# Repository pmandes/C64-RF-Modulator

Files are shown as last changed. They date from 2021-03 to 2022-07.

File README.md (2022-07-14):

# C64-RF-Modulator with S-Video Mod

This is a project of a modulator replacement based on an analog c0pperdragon module. It was adjusted in size to the Commodore C64C motherboard and extended with S-Video and Strereo Audio outputs.

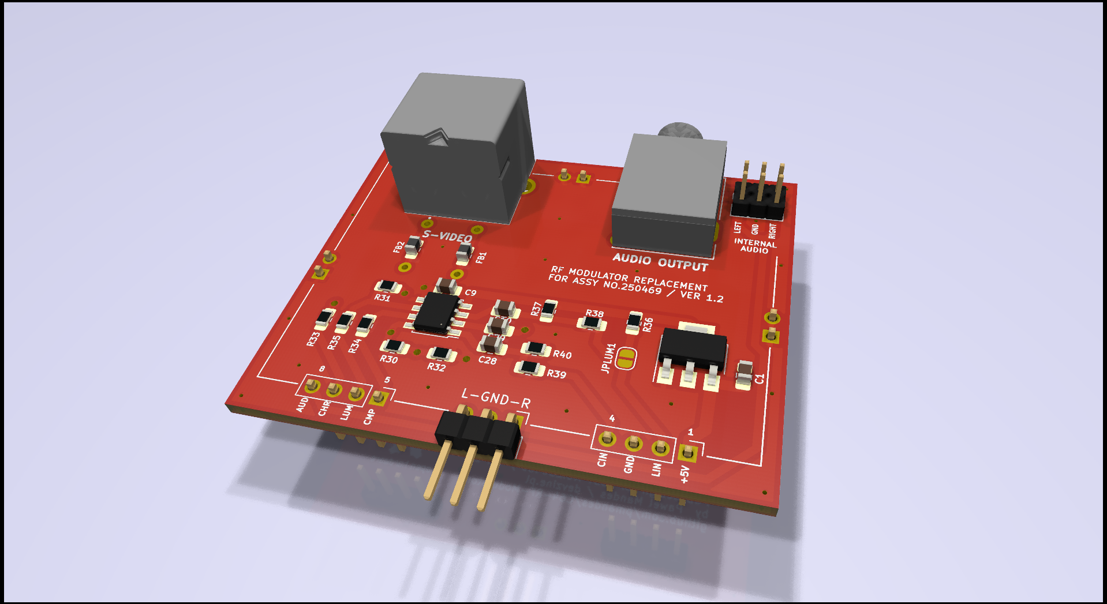
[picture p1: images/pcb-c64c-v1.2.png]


### Changelog:

1.2
- internal audio route to left and/or right channel
- ferrite beads to suppresses high-frequency electronic noise
- silkscreen layer with descriptions of all outputs and elements
- 3D models for a nice rendering
- project cleaned up and migrated to KiCad 6.0
- interactive BOM

1.1
- prototype fixes

1.0
- PCB size adjusted to C64C motherboards (ASSY No.250469)
- S-Video connector added (mini-DIN 4)
- added standard stereo audio mini-jack 3.5mm output

### Bill of materials:

<p align="center">
<a href="https://htmlpreview.github.io/?https://raw.githubusercontent.com/pmandes/C64-RF-Modulator/main/bom/ibom.html
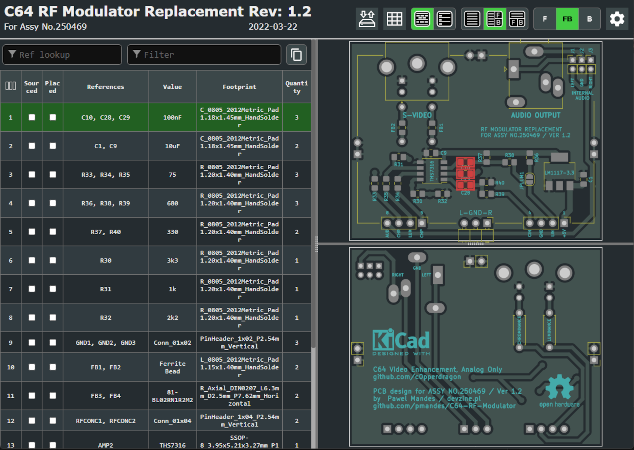
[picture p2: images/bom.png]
"></a>
</p>

### Final revision:

- all jumpers removed: audio output from an external source (e.g. MixSID)
- all jumpers on: mono signal from the motherboard connected to the left and right channels

<p align="center">
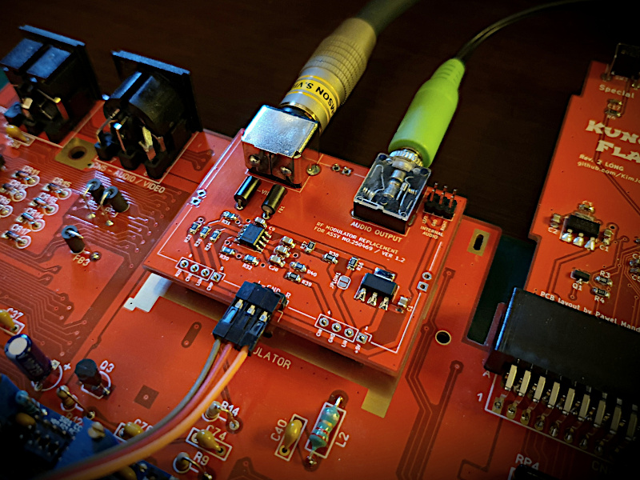
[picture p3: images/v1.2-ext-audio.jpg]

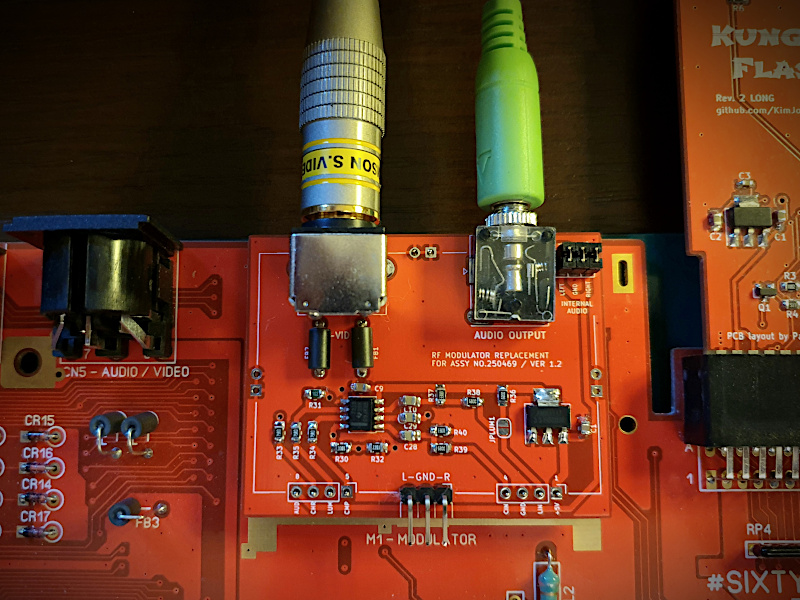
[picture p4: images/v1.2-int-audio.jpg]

</p>

### Prototype images:

The board connected to SixtyClone. Image from S-Video output:

<p align="center">
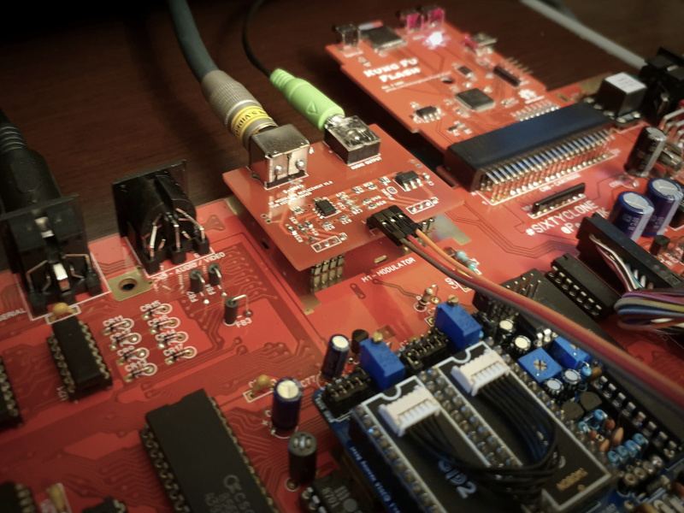
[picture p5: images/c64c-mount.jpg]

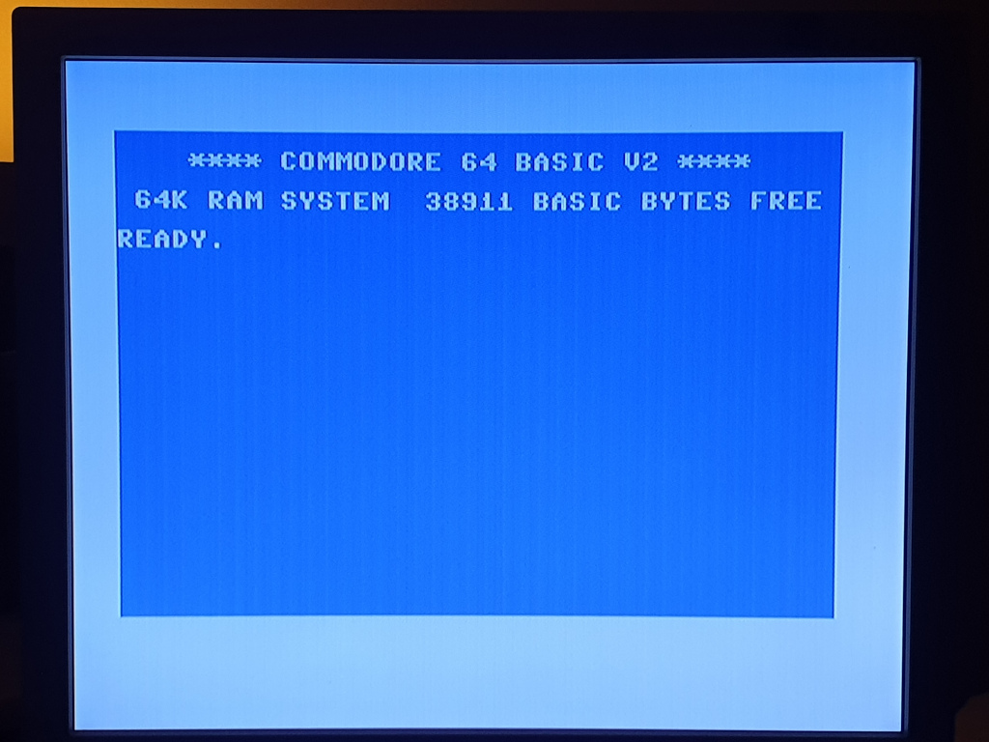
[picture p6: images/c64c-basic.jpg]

</p>

The board can be soldered with pins to the motherboard. Then the S-Video and Audio outputs will be at the level of the corresponding openings in the housing.

<p align="center">
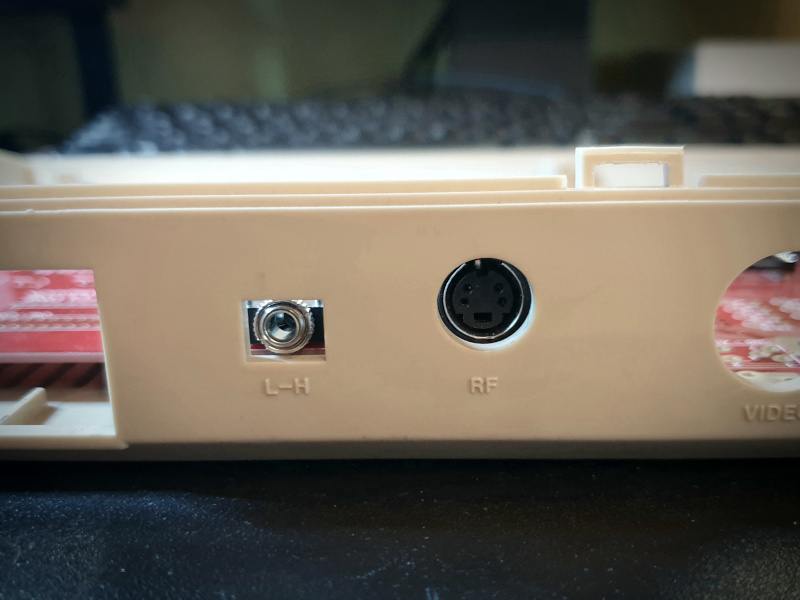
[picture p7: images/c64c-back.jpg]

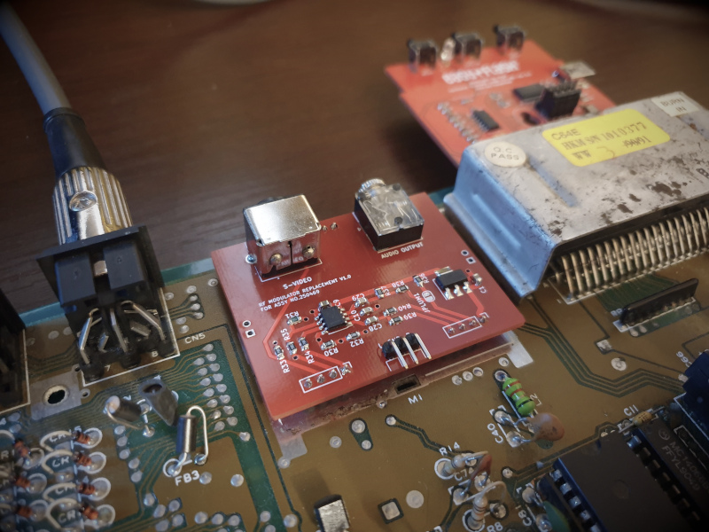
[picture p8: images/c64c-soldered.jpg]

</p>

### Links:
- c0pperdragon analog module: https://github.com/c0pperdragon/C64-Video-Enhancement/tree/master/analog_only
- order PCBs directly from PCBWay: https://www.pcbway.com/project/shareproject/Commodore_C64C_modulator_replacement_0f6cacf9.html

<a href="https://www.pcbway.com/project/shareproject/Commodore_C64C_modulator_replacement_0f6cacf9.html">PCB from PCBWay</a>

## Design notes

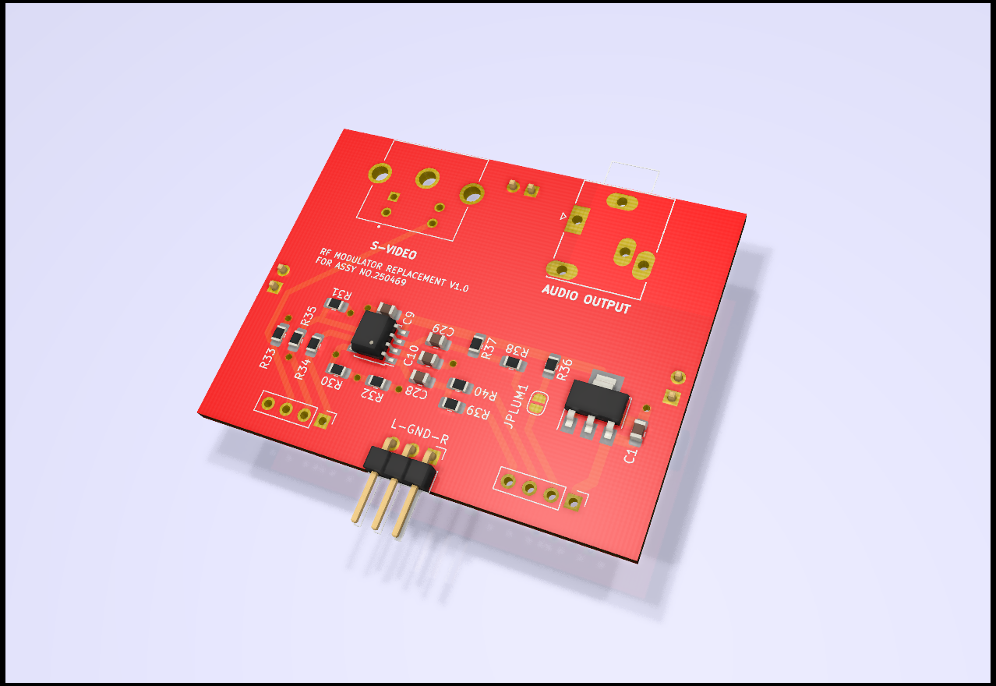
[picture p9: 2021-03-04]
images/pcb-c64c-v1.png

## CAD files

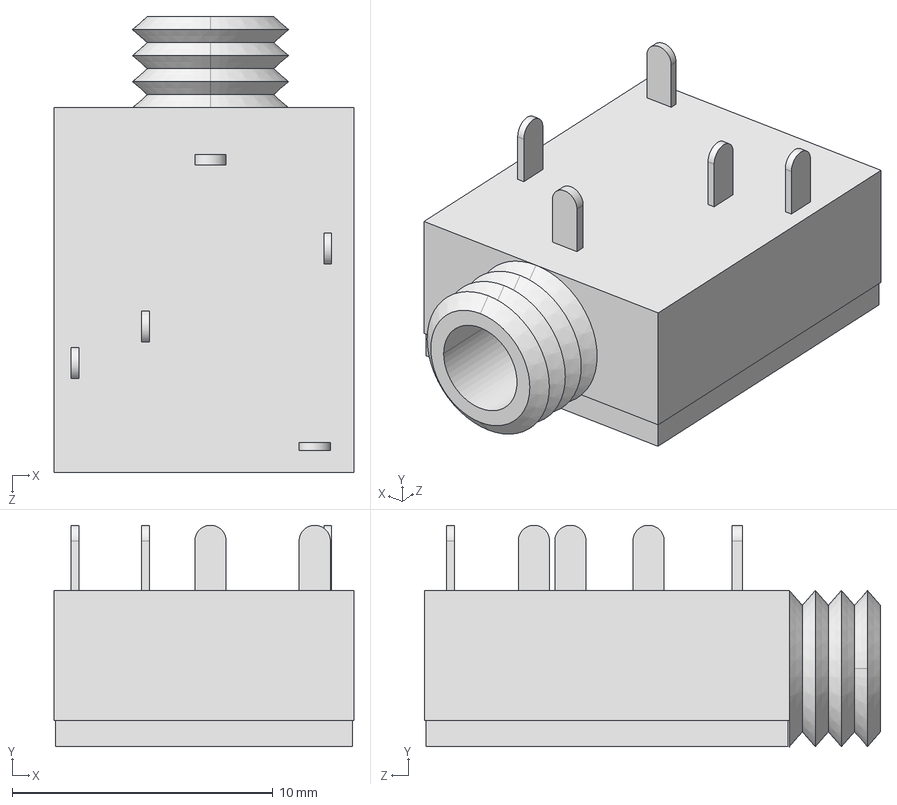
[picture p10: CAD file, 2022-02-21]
rfreplacement/3d/35RAPC4BH3.stp
11.5 x 8.50 x 17.5 mm

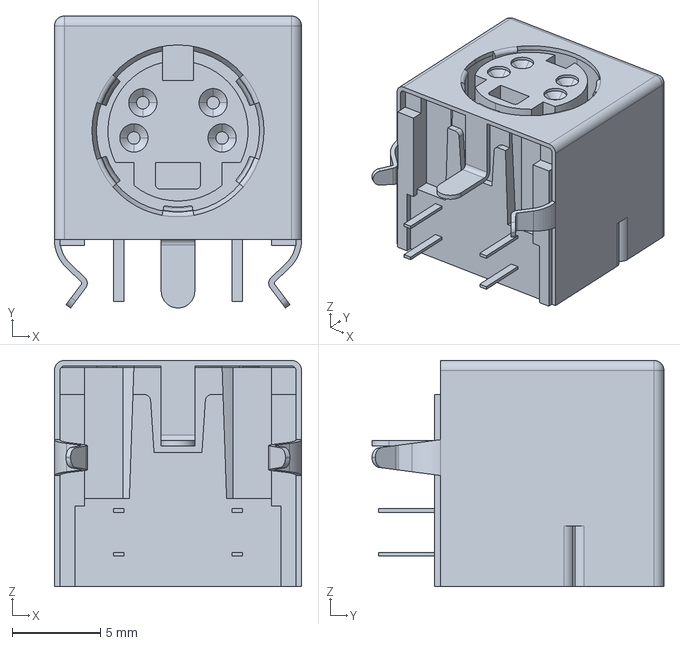
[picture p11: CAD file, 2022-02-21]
rfreplacement/3d/5749181-1.stp
14.0 x 16.6 x 12.8 mm

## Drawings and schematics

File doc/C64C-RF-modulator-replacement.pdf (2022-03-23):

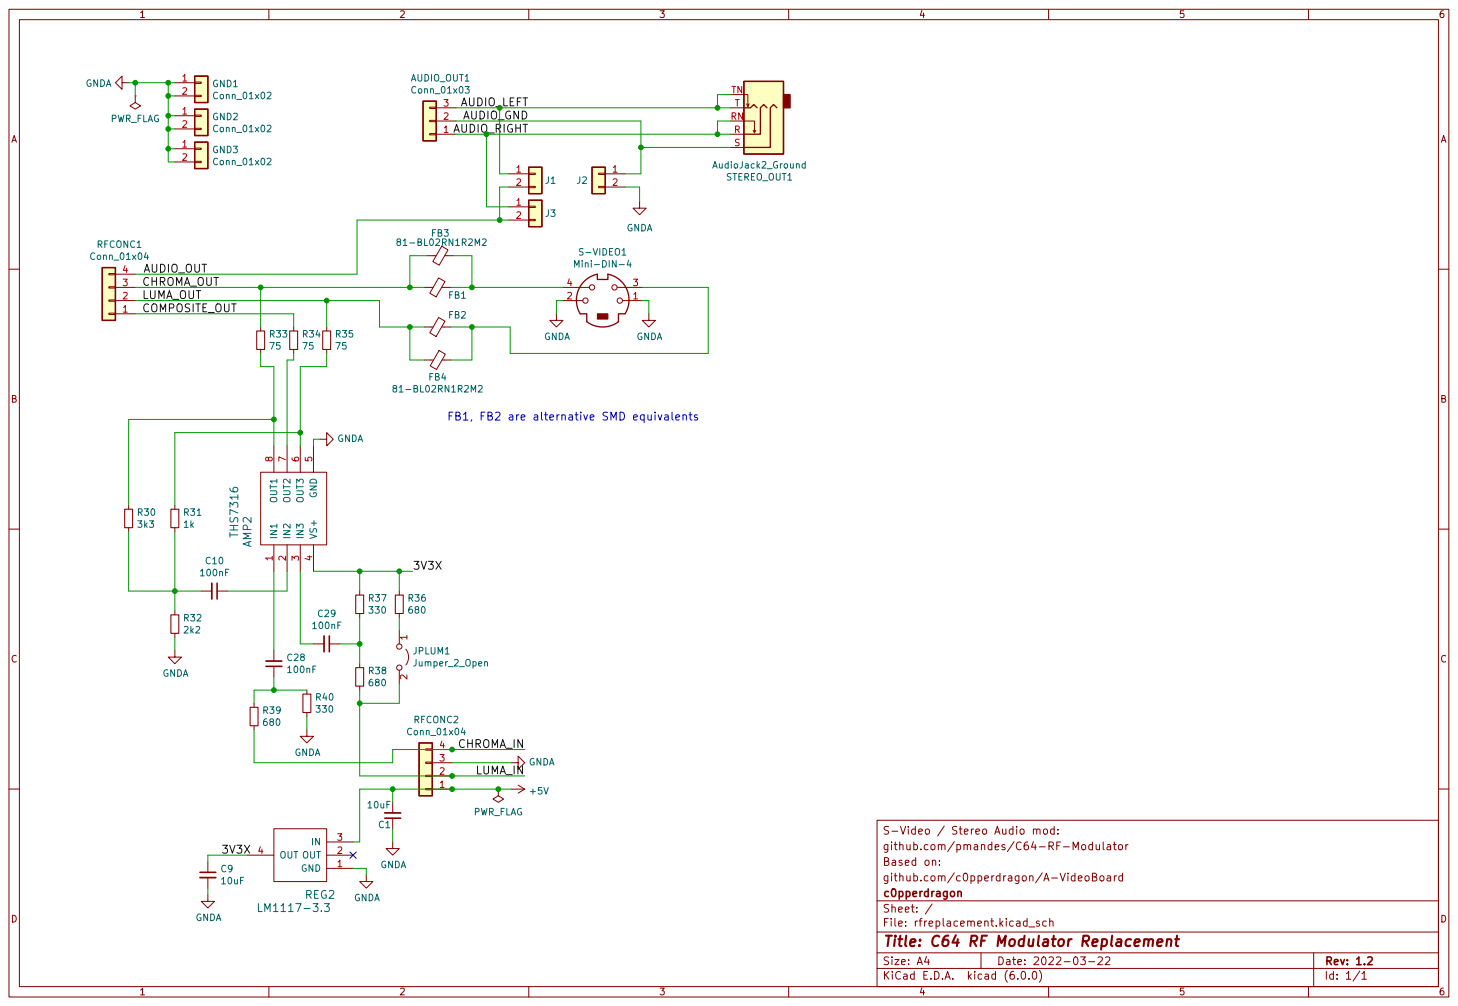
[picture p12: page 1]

2 AUDIO_GND | RN

3 CHROMA_OUT
2 | LUMA_OUT
1 COMPOSITE_OUT

FB1, FB2 are alternative SMD equivalents

github.com/c0pperdragon/A-VideoBoard Based on: github.com/pmandes/C64-RF-Modulator S-Video / Stereo Audio mod:

Id: 1/1 Title: C64 RF Modulator Replacement

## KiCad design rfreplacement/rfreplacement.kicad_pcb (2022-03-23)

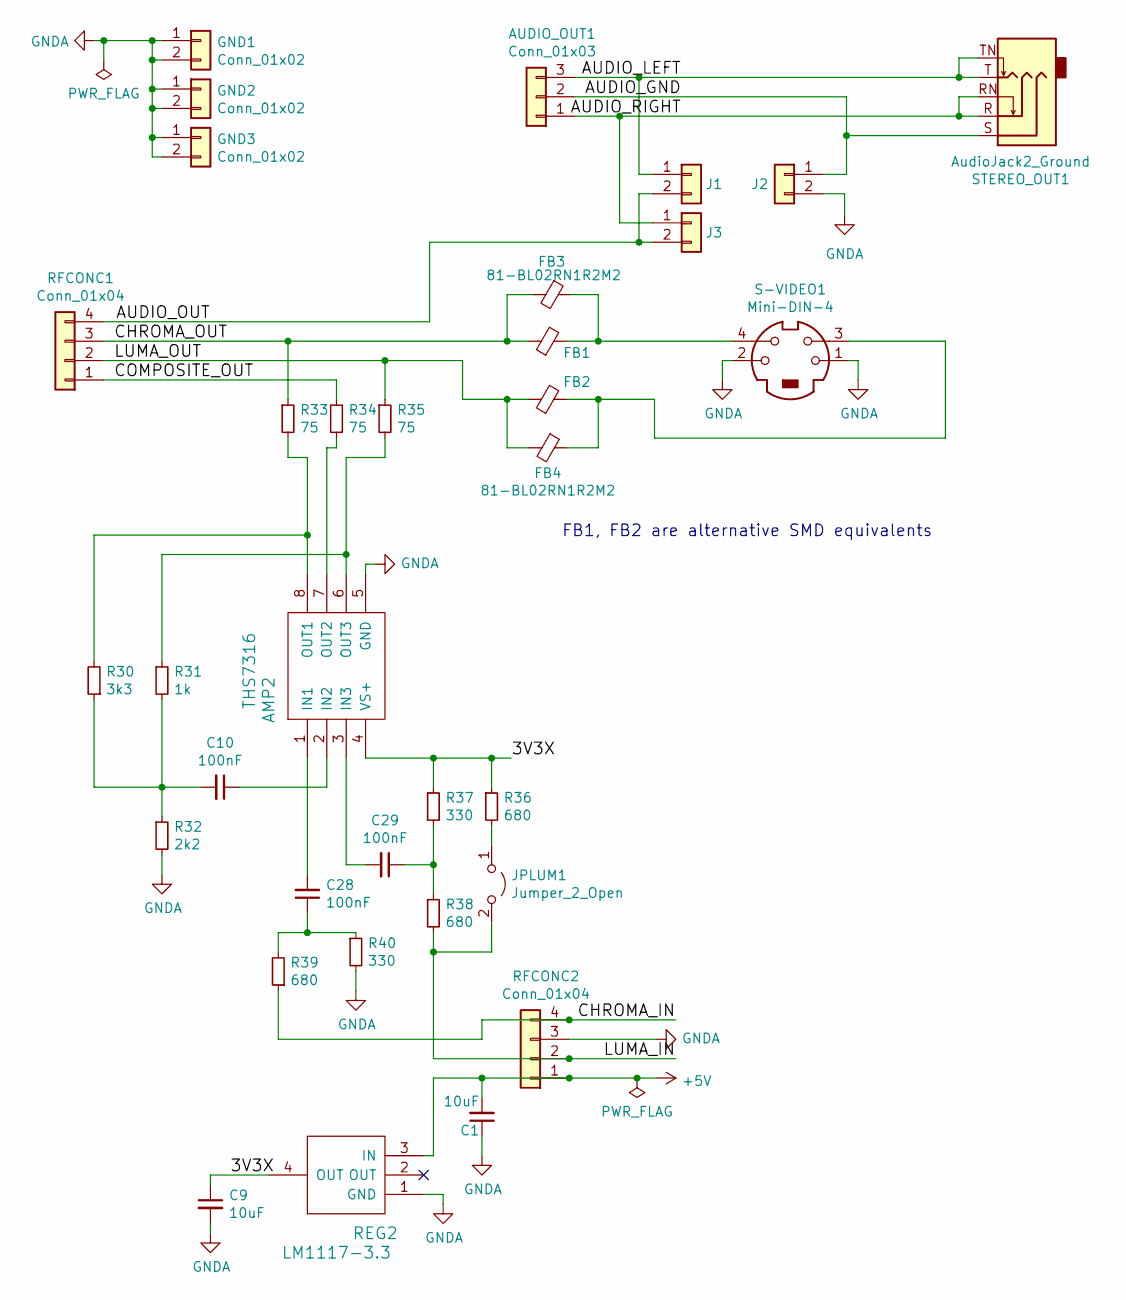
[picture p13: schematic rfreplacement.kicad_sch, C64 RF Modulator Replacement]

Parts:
AMP2: THS7316; SSOP-8_3.95x5.21x3.27mm_P1.27mm
AUDIO_OUT1: Conn_01x03; PinHeader_1x03_P2.54mm_Horizontal
C1, C9: 10uF; C_0805_2012Metric_Pad1.18x1.45mm_HandSolder
C10, C28, C29: 100nF; C_0805_2012Metric_Pad1.18x1.45mm_HandSolder
FB1, FB2: Ferrite Bead; L_0805_2012Metric_Pad1.15x1.40mm_HandSolder
FB3, FB4: 81-BL02RN1R2M2; R_Axial_DIN0207_L6.3mm_D2.5mm_P7.62mm_Horizontal
GND1, GND2, GND3: Conn_01x02; PinHeader_1x02_P2.54mm_Vertical
J1, J2, J3: Conn_01x02; PinHeader_1x02_P2.00mm_Vertical
JPLUM1: Jumper_2_Open; SolderJumper-2_P1.3mm_Open_RoundedPad1.0x1.5mm
R30: 3k3; R_0805_2012Metric_Pad1.15x1.40mm_HandSolder
R31: 1k; R_0805_2012Metric_Pad1.15x1.40mm_HandSolder
R32: 2k2; R_0805_2012Metric_Pad1.15x1.40mm_HandSolder
R33, R34, R35: 75; R_0805_2012Metric_Pad1.15x1.40mm_HandSolder
R36, R38, R39: 680; R_0805_2012Metric_Pad1.15x1.40mm_HandSolder
R37, R40: 330; R_0805_2012Metric_Pad1.15x1.40mm_HandSolder
REG2: LM1117-3.3; SOT-223
RFCONC1, RFCONC2: Conn_01x04; PinHeader_1x04_P2.54mm_Vertical
S-VIDEO1: Mini-DIN-4; TE_5749181-1
STEREO_OUT1: AudioJack2_Ground; Jack_3.5mm_Ledino_KB3SPRS_Horizontal

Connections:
+5V: C1.2, REG2.3 (IN), RFCONC2.1; also elsewhere on the board
/3V3X: AMP2.4 (VS+), C9.1, R36.1, R37.1, REG2.4 (OUT); also elsewhere on the board
/AUDIO_GND: AUDIO_OUT1.2, J2.1, STEREO_OUT1.S
/AUDIO_LEFT: AUDIO_OUT1.3, J1.1, STEREO_OUT1.T, STEREO_OUT1.TN
/AUDIO_OUT: J1.2, J3.2, RFCONC1.4
/AUDIO_RIGHT: AUDIO_OUT1.1, J3.1, STEREO_OUT1.R, STEREO_OUT1.RN
/CHROMA_IN: R39.1, RFCONC2.4
/CHROMA_OUT: FB1.1, FB3.2, R33.1, RFCONC1.3
/COMPOSITE_OUT: R34.2, RFCONC1.1
/LUMA_IN: JPLUM1.2 (B), R38.2, RFCONC2.2
/LUMA_OUT: FB2.1, FB4.2, R35.1, RFCONC1.2
GNDA: AMP2.5 (GND), C1.1, C9.2, GND1.1, GND1.2, GND2.1, GND2.2, GND3.1, GND3.2, J2.2, R32.2, R40.2, REG2.1 (GND), RFCONC2.3, S-VIDEO1.1, S-VIDEO1.2; also elsewhere on the board
unnamed 12: AMP2.1 (IN1), C28.2; also elsewhere on the board
unnamed 13: AMP2.2 (IN2), C10.1; also elsewhere on the board
unnamed 14: AMP2.3 (IN3), C29.2; also elsewhere on the board
unnamed 15: AMP2.6 (OUT3), R31.1, R35.2; also elsewhere on the board
unnamed 16: AMP2.7 (OUT2), R34.1; also elsewhere on the board
unnamed 17: AMP2.8 (OUT1), R30.2, R33.2; also elsewhere on the board
unnamed: C10.2, R30.1, R31.2, R32.1
unnamed: C28.1, R39.2, R40.1
unnamed: C29.1, R37.2, R38.1
unnamed: FB1.2, FB3.1, S-VIDEO1.4
unnamed: FB2.2, FB4.1, S-VIDEO1.3
unnamed: JPLUM1.1 (A), R36.2

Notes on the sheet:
FB1, FB2 are alternative SMD equivalents

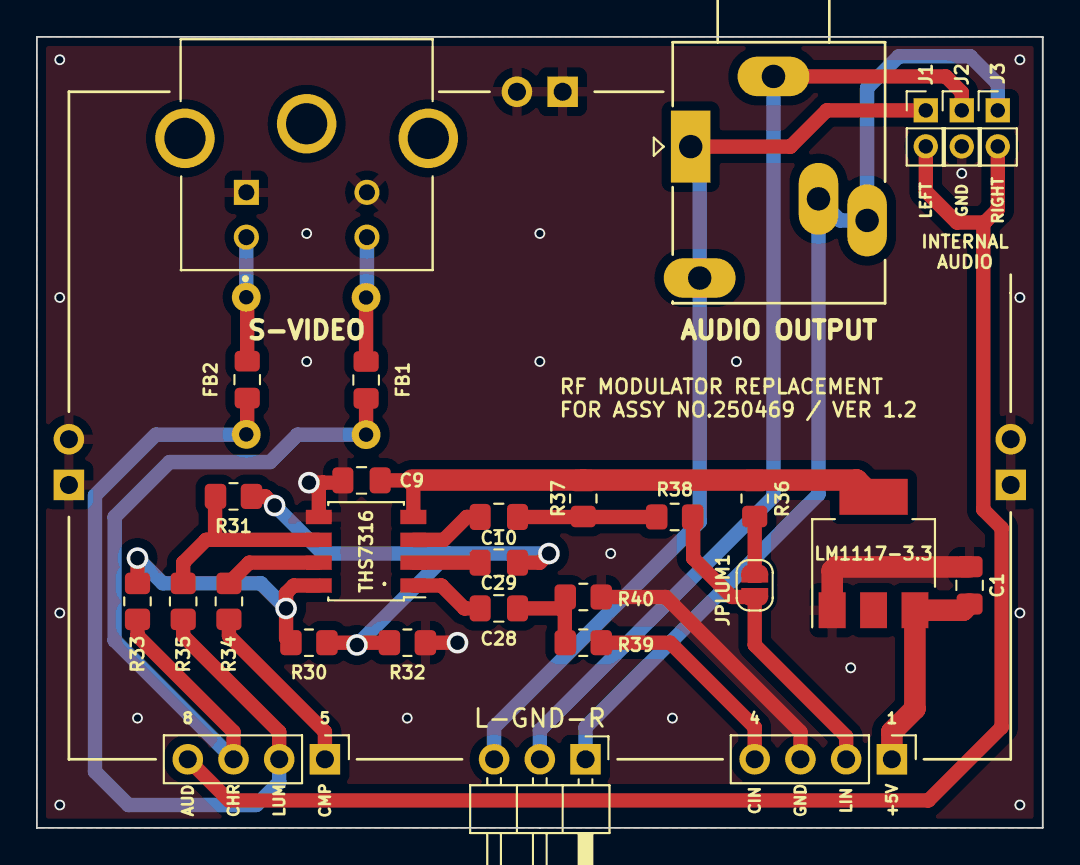
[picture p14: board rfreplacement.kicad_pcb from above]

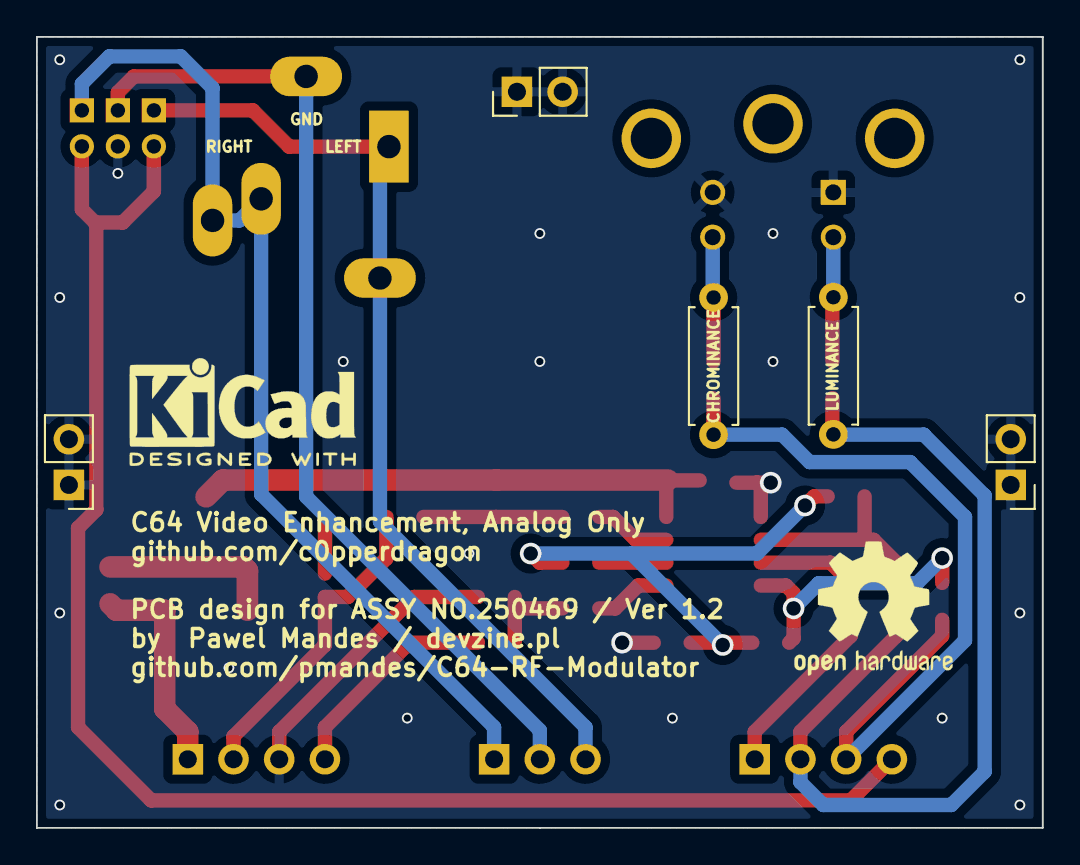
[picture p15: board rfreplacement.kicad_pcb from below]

Board: 2 copper layers, 55.9 x 43.9 mm, 34 parts (5 on the bottom side), 24 nets.

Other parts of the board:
LM1117-3.3: LM1117-3.3; SOT-223
THS7316: THS7316; SSOP-8_3.95x5.21x3.27mm_P1.27mm

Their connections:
+5V: LM1117-3.3.3 (IN); also elsewhere on the board
/3V3X: LM1117-3.3.4 (OUT), THS7316.4 (VS+); also elsewhere on the board
GNDA: LM1117-3.3.1 (GND), THS7316.5 (GND); also elsewhere on the board
unnamed 12: THS7316.1 (IN1); also elsewhere on the board
unnamed 13: THS7316.2 (IN2); also elsewhere on the board
unnamed 14: THS7316.3 (IN3); also elsewhere on the board
unnamed 15: THS7316.6 (OUT3); also elsewhere on the board
unnamed 16: THS7316.7 (OUT2); also elsewhere on the board
unnamed 17: THS7316.8 (OUT1); also elsewhere on the board

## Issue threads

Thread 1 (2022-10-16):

Item 10 on BOM - what is it?

Erroneous-Hyphen, 2022-10-16:
Im not sure if this is just me not understanding - on the BOM item 11 is a ferrite bead, easy enough
Item 10 is an SMD component but is marked 'Ferrite Bead'.  Im not entirely sure what this is supposed to be - is it a line filter of some value? or an inductor?  my apologies if Im just failing to read the BOM correctly but I cant work it out for the life of me.

pmandes, 2022-10-18:
Hi,

There are two options:

- you can use THT ferrite beads like in C64C (FB3, FB4):
i.e. [](https://www.mouser.pl/ProductDetail/Murata-Electronics/BL02RN1R2M2B?qs=rQrCv%2FN695EG0eyD3E3V4g%3D%3D)

**OR**

- use an equivalent SMD element with similar characteristics (impedance 70Ω at 100MHz) (FB1, FB2)

They are used to filter out high-frequency disturbances and noise.

Closed 2022-12-13.

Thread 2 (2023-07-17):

Assembled PCB

jp39, 2023-07-17:
Hi,

Is there any way to obtain this board already assembled ? PCBWay offers an assembly service but they need to be provided with a BOM file in the right format.

Thanks,

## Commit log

2021-02-28 Breadbin connectors removed, S-Video/Stereo Audio output connectors added, new PCB layout for C64C motherboards.
    [rfreplacement.kicad_pcb, rfreplacement.sch]
2021-02-28 Pinheaders moved to the bottom side.
    [rfreplacement.kicad_pcb]
2021-03-03 Layout cleanup.
    [rfreplacement.kicad_pcb]
2021-03-04 PCB labels cleanup.
    [rfreplacement.kicad_pcb]
2021-03-05 Gerber files added.
    [rfreplacement-B_Cu.gbr, rfreplacement-B_Mask.gbr, rfreplacement-B_SilkS.gbr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]
2021-03-09 Dimensions adjusted.
    [rfreplacement.kicad_pcb]
2021-03-15 Connectors position adjusted.
    [rfreplacement.kicad_pcb]
2021-03-15 New gerber files.
    [rfreplacement-B_Cu.gbr, rfreplacement-B_Mask.gbr, rfreplacement-B_SilkS.gbr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]
2022-02-21 PCB ver 1.2
    [35RAPC4BH3.stp, 5749181-1.stp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]
2022-02-21 New gerber file
    [rfreplacement-B_Signal.gbr, rfreplacement-B_Silkscreen.gbr, rfreplacement-B_Soldermask.gbr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]
2022-02-21 Gerbers updated. Prototype images.
    [rfreplacement-B_Cu.gbl, rfreplacement-B_Mask.gbs, rfreplacement-B_Paste.gbp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]
2022-03-23 Ver1.2 final. Interactive BOM.
    [rfreplacement-B_Cu.gbl, rfreplacement-B_Mask.gbs, rfreplacement-B_Paste.gbp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]
